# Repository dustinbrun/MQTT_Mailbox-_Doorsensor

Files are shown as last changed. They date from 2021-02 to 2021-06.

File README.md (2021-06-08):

# MQTT_Mailbox-_Doorsensor

A MQTT Door- or Mailboxsensor using an ESP8266 Wifi Module, which notifies you if you receive a Letter or someone opens the Door

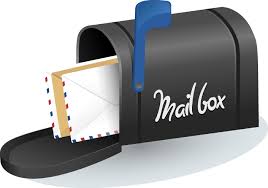
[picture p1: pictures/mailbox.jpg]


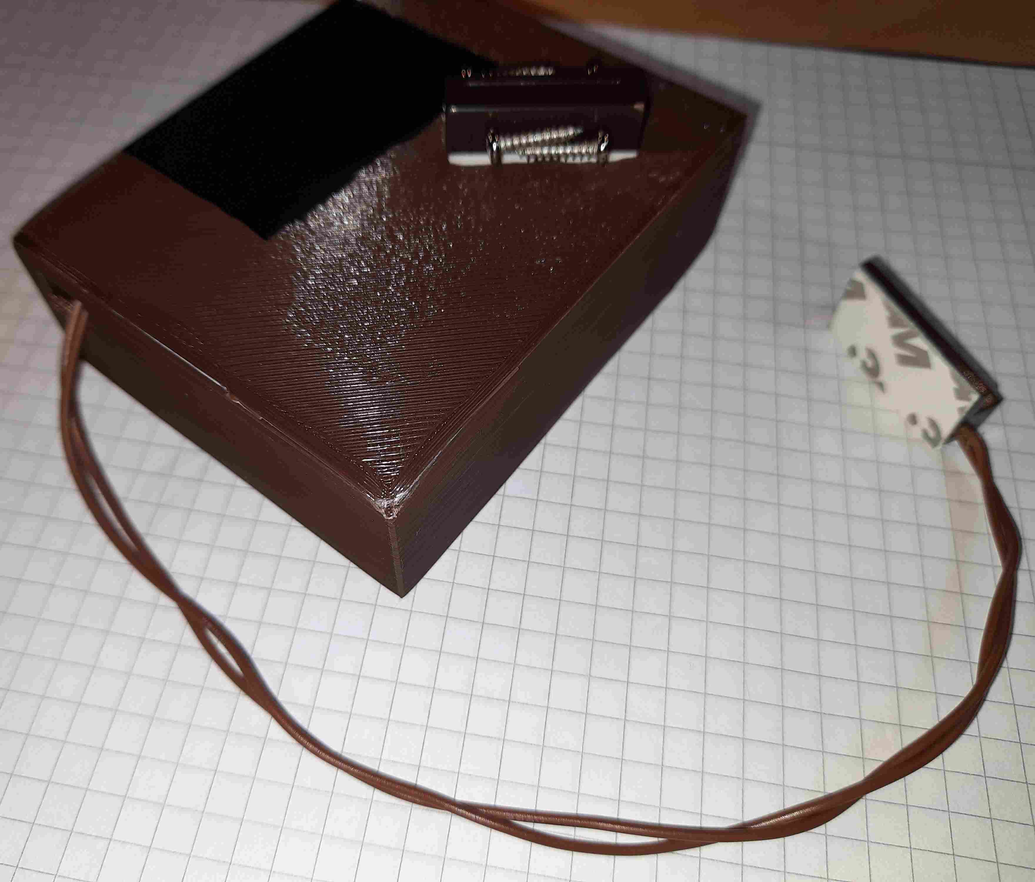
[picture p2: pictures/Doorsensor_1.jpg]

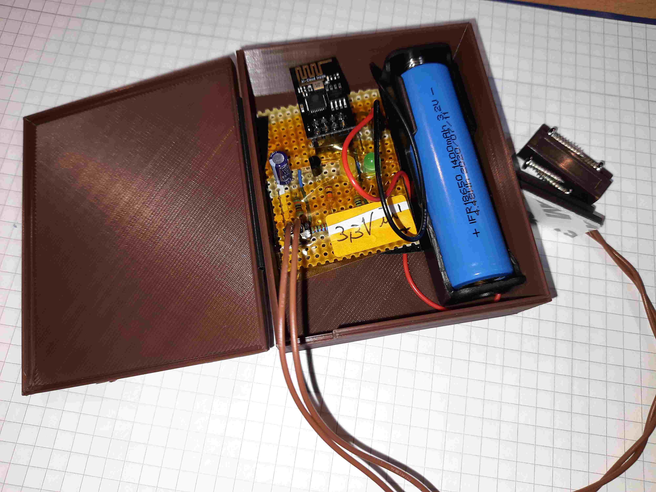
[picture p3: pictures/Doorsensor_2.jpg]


# How it Works
If the mailbox opens the ESP wakes up from deep-sleep, connects to Wifi and the MQTT-server and sents out a MQTT message, which is then processed by Node-Red. Node-Red however "converts" it into a Matrix message, which is then posted to my phone via a Matrix-Chatbot.
## You Can find the Instructions how to create the Chatbot in the [node-red-Folder](node-red/README.md).

As a switch I used a magentic REED-switch, which CLOSES if a magnet gets close to it. This was the first problem because when the mailbox is closed (which is the case for the most time) the reedswitch is also closed. If we now want to get notified when the mailbox opens we need to use the opening reedswitch as a trigger to send the message.

The Sensor is powered by a LiFePo4 Battery and therefor it must draw verry little Power while doing nothing to guarantee a long battery lifetime.

For those two problems I came up with two ideas:

# First Idea - FAIL
My fist idea was to cut off the power of the ESP while the Mailbox is closed so it doesn´t draw any power. To do this I used a Transistor in series with the ESP which can be bypassed by the switch. I was inspired by Andreas Spiess´s [video](https://youtu.be/Kvl-mR5gldw?t=1242). He explains in this video how to do just that.
However there was another probem because the reedswitch in my configuration was normally closed. I needed to assing two transistor in the following configuration to create a normally high singal:
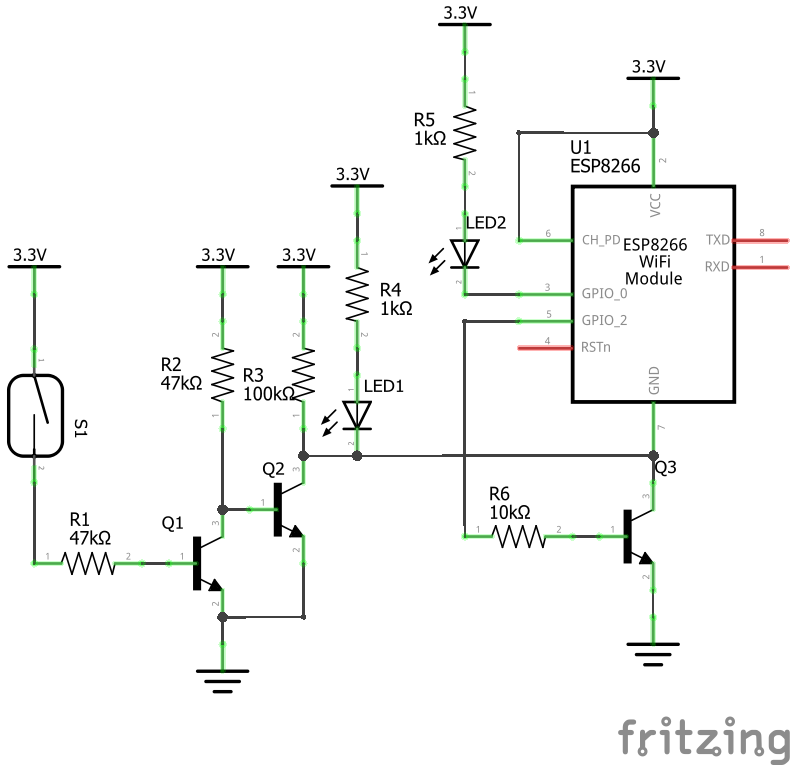
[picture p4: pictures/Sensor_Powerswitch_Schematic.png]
<br>

However this idea didn´t work out, because the transistor was not able to keep the ESP powered on as long as it sends the data, so i came up with another idea:

# Second idea - Better, but still not good
I simply connected the normally high singal of the transistors directly to the resetpin of the ESP. If the reedswitch opens the resetpin is pulled low, which resets the ESP. After the reset it boots up, sends out the data and goes to deep sleep, when finished. This way the power consumption was verry low. 

But there was one problem: Sometimes the post man doesn´t throw the newspaper all the way in to the mailbox, wich causes a opened mail slot and consequently an always opened reedswitch. This caues, that the resetpin is pulled low continously. This leads to a realetively high current draw, wich would drain the battery quiet fast.
So I needed to get rid of this problem to:

# Third idea - IT Works!!
I needed to create a pulse trigger singal, when the mailbox gets opened and if it stays opend, the reedswitch-signal doesn´t stay low, and goes high again after a short period of time.
To get this result I used the following FINAL schematic:

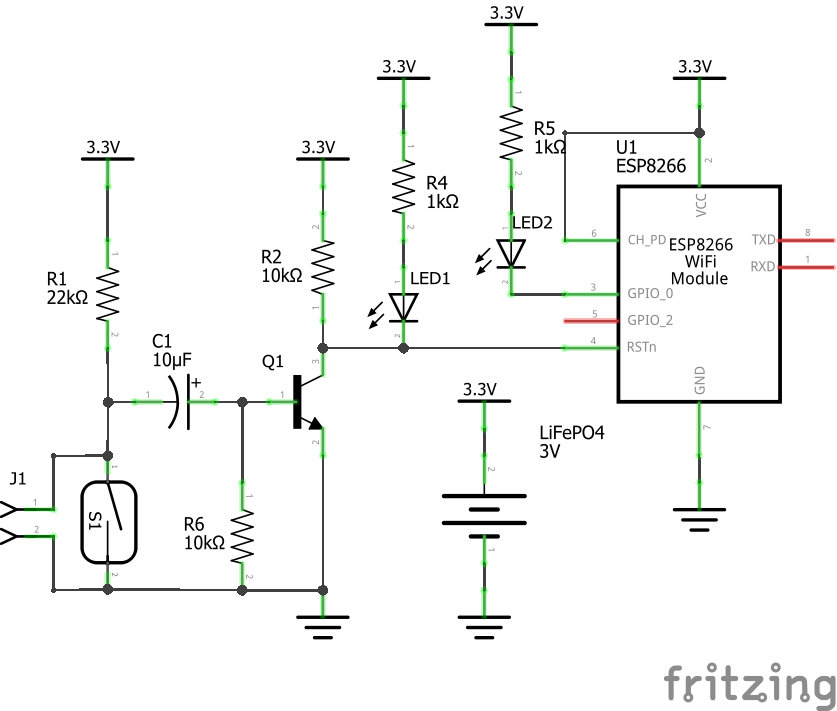
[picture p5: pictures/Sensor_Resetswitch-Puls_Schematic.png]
Final schematic

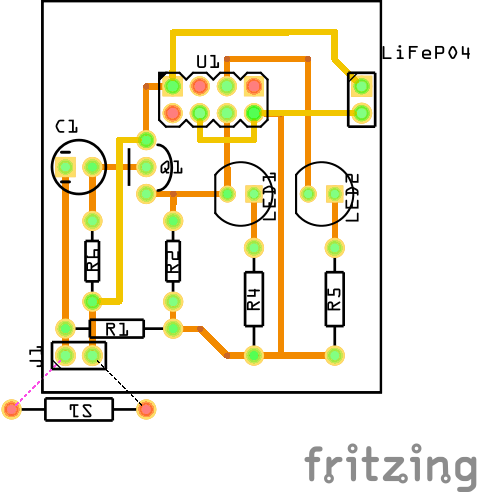
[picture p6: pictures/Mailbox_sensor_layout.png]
Final PCB Layout


The signal at the resetpin, when the reedswitch opens looks like that. By varying the value of the capacitor you can also change the pulse length:
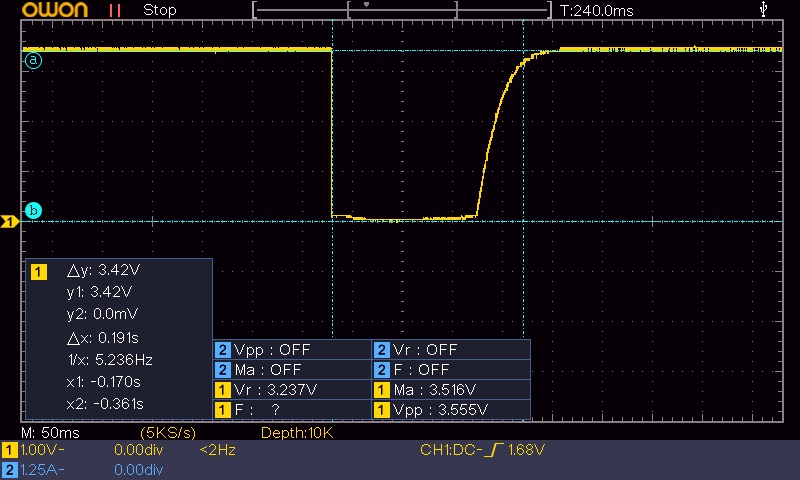
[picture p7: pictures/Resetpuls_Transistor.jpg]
Reset signal


# The code
The code is verry simple: After a reset it connects to wifi and an MQTT server where it publishes a message. After that it causes the ESP to enter an infinite deep sleep, which can only be interrupted by another reset of the ESP board. I used an ESP8266 Wifi Module but the code should work with any other ESP too. 

All the processing of the message is done on the MQTT server/Node Red.

# Power consumption
The powerconsumtion of the circuit looks like that:
    - 70mA while the ESP is active (and sending out data)
    - 0.2mA with the ESP in Deep-Sleep and the reedswitch closed
    - (0.04mA  with the ESP in Deep-Sleep and the reedswitch opend)

The circuit can be connected to the LiFePo4 battery directly without any voltage regulation because the nominal voltage of the battery is around 3.3V.

To power the circuit I use a LiFePo4 bettery of the type **IFR18650** with a capacity of 1400mAH (4.48Wh).
So in theory this should give an approximate runtime of 9 months!!

<p xmlns:dct="http://purl.org/dc/terms/" xmlns:cc="http://creativecommons.org/ns#" class="license-text">This work by <span property="cc:attributionName">Dustin Brunner</span> is licensed under <a rel="license" href="https://creativecommons.org/licenses/by/4.0">CC BY 4.0</a></p>

<br />Dieses Werk von <span xmlns:cc="http://creativecommons.org/ns#" property="cc:attributionName">Dustin Brunner</span> ist lizenziert unter einer <a rel="license" href="http://creativecommons.org/licenses/by/4.0/">Creative Commons Namensnennung 4.0 International Lizenz</a>.

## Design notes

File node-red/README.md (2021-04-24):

# Integration in Node Red / Node-Red Matrix Chatbot

This is a follow-up Article of the MQTT Mailbox-Doorsensor-Project.

I want to show you how you can integrate the Doorsensor into Node-Red, where it triggers a Matrix Chatbot, which is then sending you a Message, that you have got a letter in the mailbox.

If you didn’t already have a Matrix-Server, I recommend you to read my article about setting up a [Matrix Chatserver using Docker](https://www.brunweb.de/eigener-matrix-homeserver-mit-docker-einrichten/) (in German).

The Mailbox-Sensor is programmed in a way, that it publishes a MQTT-message on a specific topic, whenever the mailbox gets opened. Node Red is processing the message and sending out a message into a Matrix-Chatroom.

# 1. Setup Bot-User on the Matrix server

You first have to create a specific user on your matrix-server, that is only used by the bot. Name it as you want. If you have followed my Matrix-server setup instructions, you can do that in the synapse-admin webpanel.

Now you need to create a Chatroom for you and the Bot (The Personal chat with the bot is not working, due to End-to-End encryption). You can create this room with your personal account on the Matrix-server. Make sure to NOT enable room encryption. Now invite the Bot-user into the room.

After that login into the element-webpanel with your newly created bot-user and accept the invitation into the room.

# 2. Setup Node-Red

To configure the bot in Node-Red you first need to find out the Room-ID of your bot-room. For that click on the little „i“ in the top right corner of the element-webpanel. Then click on „room-properties“ and in the „advanced“ tab, you find the „Internal Room ID“. Copy it because you will need it later.

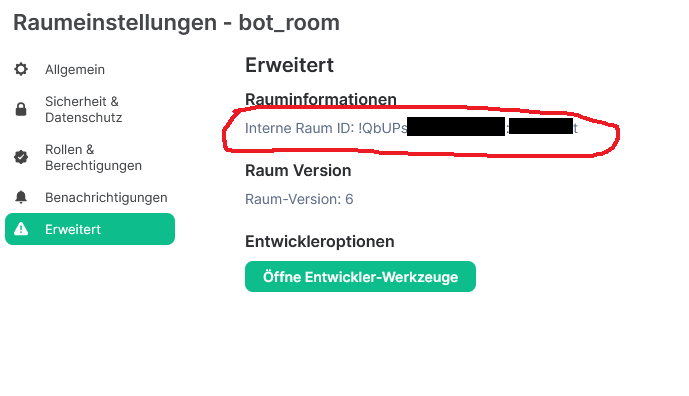
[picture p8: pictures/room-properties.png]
Room Properties


In Node Red you first need to download the Node „node-red-contrib-matrix“. (There is also the „node-red-contrib-matrixbot“ Node availible, but this did **not** work for me because it wont connect to my matrix server).

Now you can import my flow, which is the file: `matrix-doorsensor-flow.json`.

matrix-doorsensor-flow

You need to configure the „bot_room out“-Node: Fill your previously copied room-id into the „Room“ field. Then click on the server-field, where you need to fill in your server-address. Dont fill the User-Token field by yourself. Instead fill in the username and password of your bot-user and click on the little arrow in the „Generate Token“ tab. This will create a user-token for you. If you ever have connectivity problems to your matrix-server, just delete the Token from the token field and generate a new one like described earlier.

You can test if your configuration is working by clicking on the inject „1“- node. You should receive a message in your bot-room.

If it does not work make sure that the bot-user is not logged in on the element-webpanel anymore. I have noticed, that the when I login the bot-user on any other client, the generated access token is not valid anymore. If this happens just create a new one and you will be fine :).

# Going further

You can expand your bot by adding an input-node to the mix. Now you can text commands into the bot-room and the bot answers to them.

In my configuration I added a opportunity to Request the current weather from my weatherstation. Also the bot textes me at 8 o’clock in the morning automatically the current temperature.

My complete flow looks like this:

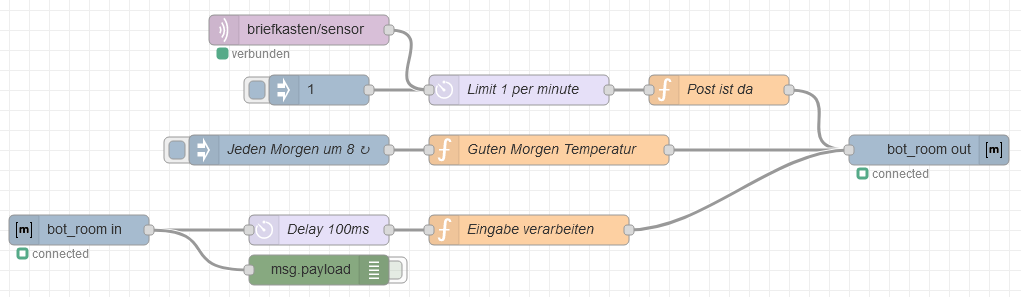
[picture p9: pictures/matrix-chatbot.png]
matrix-chatbot


You can download it, it is the File: `matrix-chatbot.json` from Mailbox-Doorsensor Repository.

<br>
<br>
<p xmlns:dct="http://purl.org/dc/terms/" xmlns:cc="http://creativecommons.org/ns#" class="license-text">This work by <span property="cc:attributionName">Dustin Brunner</span> is licensed under <a rel="license" href="https://creativecommons.org/licenses/by/4.0">CC BY 4.0</a></p>

<br />Dieses Werk von <span xmlns:cc="http://creativecommons.org/ns#" property="cc:attributionName">Dustin Brunner</span> ist lizenziert unter einer <a rel="license" href="http://creativecommons.org/licenses/by/4.0/">Creative Commons Namensnennung 4.0 International Lizenz</a>.

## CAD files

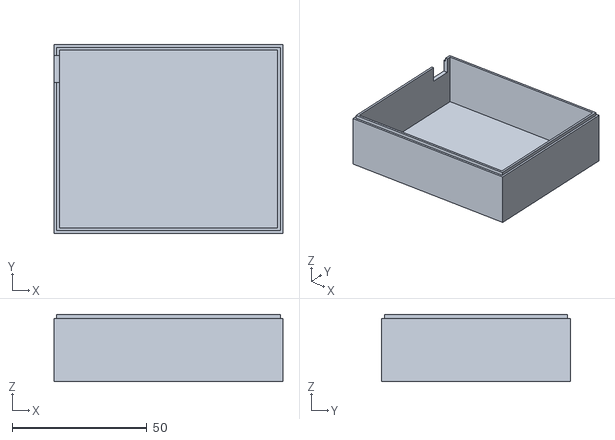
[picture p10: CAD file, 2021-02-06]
3D_model/Malibox_Sensor_Case_Bottom.stl
85.0 x 70.0 x 25.0

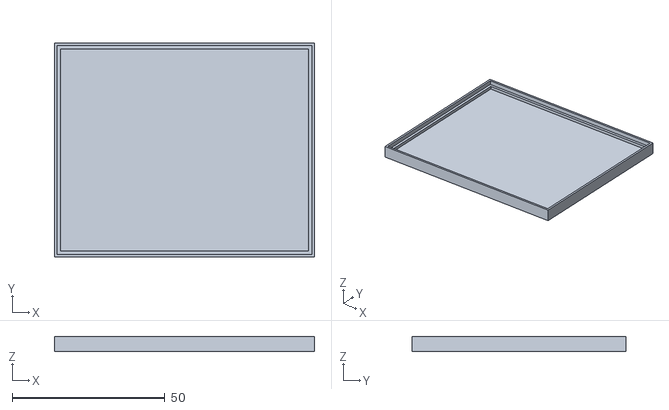
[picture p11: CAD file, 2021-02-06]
3D_model/Malibox_Sensor_Case_Top.stl
85.0 x 70.0 x 5.00

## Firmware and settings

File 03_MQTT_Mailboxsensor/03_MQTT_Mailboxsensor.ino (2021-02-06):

#include <ESP8266WiFi.h>
#include <PubSubClient.h>

const char* ssid = "WIFI NETWORK";
const char* password = "WIFI PASSWORD";

//MQTT Server
const char* mqtt_server = "MQTT Server-IP";

const int dataled = 0;

WiFiClient espClient;
PubSubClient client(espClient);

void setup() {
  pinMode(dataled, OUTPUT);
  digitalWrite(dataled, LOW);

  /*Serial.begin(115200);
  Serial.println("MQTT Mailboxsensor");
  Serial.println("Connecting WIFI");  //*/
  
  WiFi.mode(WIFI_STA);
  WiFi.begin(ssid, password);
  while (WiFi.status() != WL_CONNECTED){
    delay(500);
    //Serial.print(".");
  }
  //Serial.println("WiFi connected.");

  client.setServer(mqtt_server, 1883);
  client.connect("Mailboxsensor");

  client.publish("briefkasten/sensor", "1");
  
  client.loop();

  delay(1000);

  //Serial.println("Starting Deep Sleep ...");
  digitalWrite(dataled, HIGH);  
  ESP.deepSleep(0); //Infinite Deep-Sleep
}

void loop() {
}
